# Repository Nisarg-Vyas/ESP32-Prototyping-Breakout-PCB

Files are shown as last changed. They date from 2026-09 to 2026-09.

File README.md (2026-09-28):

# ESP32 Prototyping & Breakout Board

A custom PCB designed to make ESP32 prototyping easier, faster, and more convenient than working directly on a breadboard or perfboard.

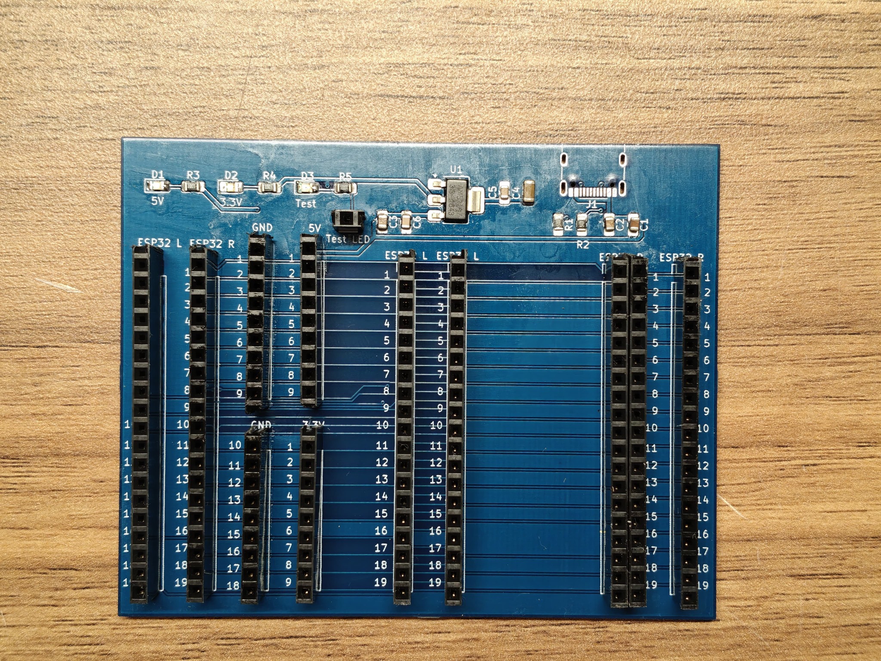
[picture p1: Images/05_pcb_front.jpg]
ESP32 Prototyping Breakout Board


## Overview

When working with ESP32 development boards, the physical form factor can make breadboard prototyping inconvenient. In particular, larger ESP32 boards can occupy a large portion of a breadboard and restrict convenient access to the pins on both sides.

A perfboard can solve some of these problems, but manually wiring a large number of closely spaced GPIO connections is tedious and time-consuming.

This project was created as a reusable PCB-based prototyping platform. The ESP32 is mounted on the board while its pins are brought out to multiple accessible header rows. The board also provides dedicated power and ground connections and supports more than one ESP32 development-board form factor.

The goal is not to replace a breadboard for every project, but to make repeated ESP32 prototyping cleaner and faster.

## Motivation

The project started from a simple practical problem:

- A larger ESP32 development board does not leave convenient access to both sides of a breadboard.
- Connecting peripherals to both sides of the ESP32 can therefore become awkward.
- Dense adjacent GPIO connections on a perfboard require a lot of manual soldering.
- A custom PCB provides a repeatable layout that can be reused across multiple ESP32 prototypes.
- Since the board was already being designed for the larger ESP32 form factor, the layout was made compatible with a smaller ESP32 board as well.

### Breadboard vs. Custom PCB

The photographs in `Images/` show the motivation for the design.

The larger ESP32 board occupies a significant area of the breadboard, limiting convenient access to the surrounding rows. The custom PCB instead places the ESP32 in the center and distributes its connections across accessible header rows.

## Features

- ESP32 pin breakout through multiple 2.54 mm header rows
- Dedicated GND connections
- Dedicated 5 V connections
- Dedicated 3.3 V connections
- USB Type-C input circuit on the PCB
- USB Type-C CC resistors
- AMS1117-3.3 V linear regulator
- Regulator input/output capacitors
- 5 V indicator LED
- 3.3 V indicator LED
- Separate test LED
- Through-hole headers with SMD supporting circuitry
- Designed for multiple ESP32 development-board form factors
- Compact custom PCB: approximately **87.62 mm × 70 mm**
- Final PCB layout completed with no unrouted connections in KiCad

> **Note:** The USB Type-C connector itself has not yet been sourced by me, so it is **not soldered onto the current physical PCB**. The connector footprint and supporting circuitry are present in the PCB design, but the current prototype does not have the Type-C connector populated.

## Hardware Design

### Block Diagram

```text
                    USB Type-C
                        |
                        v
                    5 V Rail
                   /       \
                  /         \
             5 V LED      AMS1117-3.3
                              |
                              v
                         3.3 V Rail
                              |
                              v
                           ESP32
                              |
             +----------------+----------------+
             |                |                |
          GPIO Headers     GND Headers     Power Headers
```

### Schematic

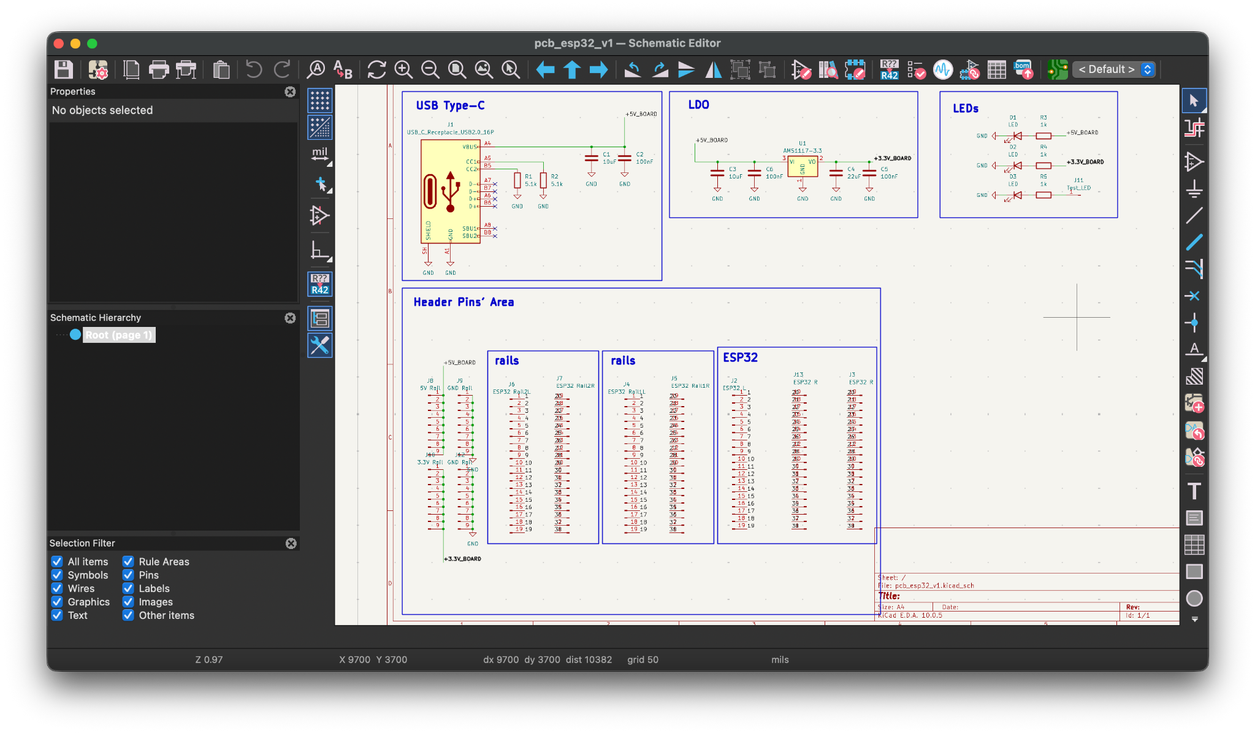
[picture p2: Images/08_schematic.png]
Schematic


The schematic is divided into:

- USB Type-C input
- 3.3 V regulation
- Indicator LEDs
- ESP32 header connections
- Power and ground rails

## PCB Design

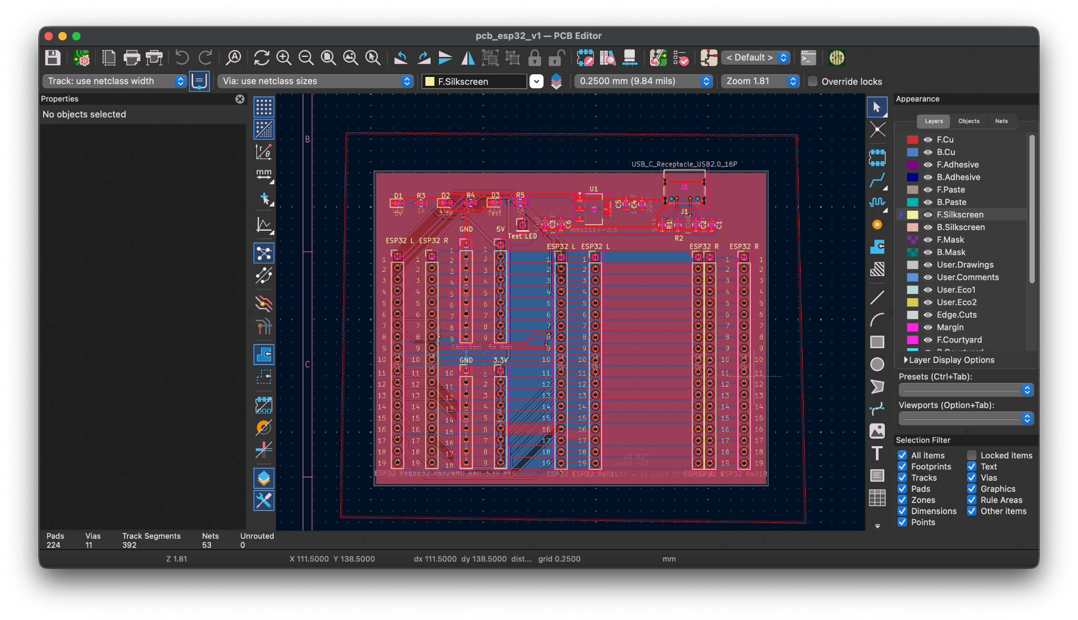
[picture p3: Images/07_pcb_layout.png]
PCB Layout


The board was designed in **KiCad**.

The layout contains multiple parallel ESP32 header rows so that the ESP32 connections remain accessible while the ESP32 is mounted on the board.

The final PCB has:

- Board size: **87.62 mm × 70 mm**
- 2.54 mm header spacing
- SMD power/regulator circuitry
- Through-hole ESP32/header connections
- USB Type-C footprint and supporting circuit
- Dedicated power and ground access

## Physical Board

### PCB without ESP32

PCB front

The board exposes the ESP32 connections through the surrounding header rows.

### PCB with larger ESP32

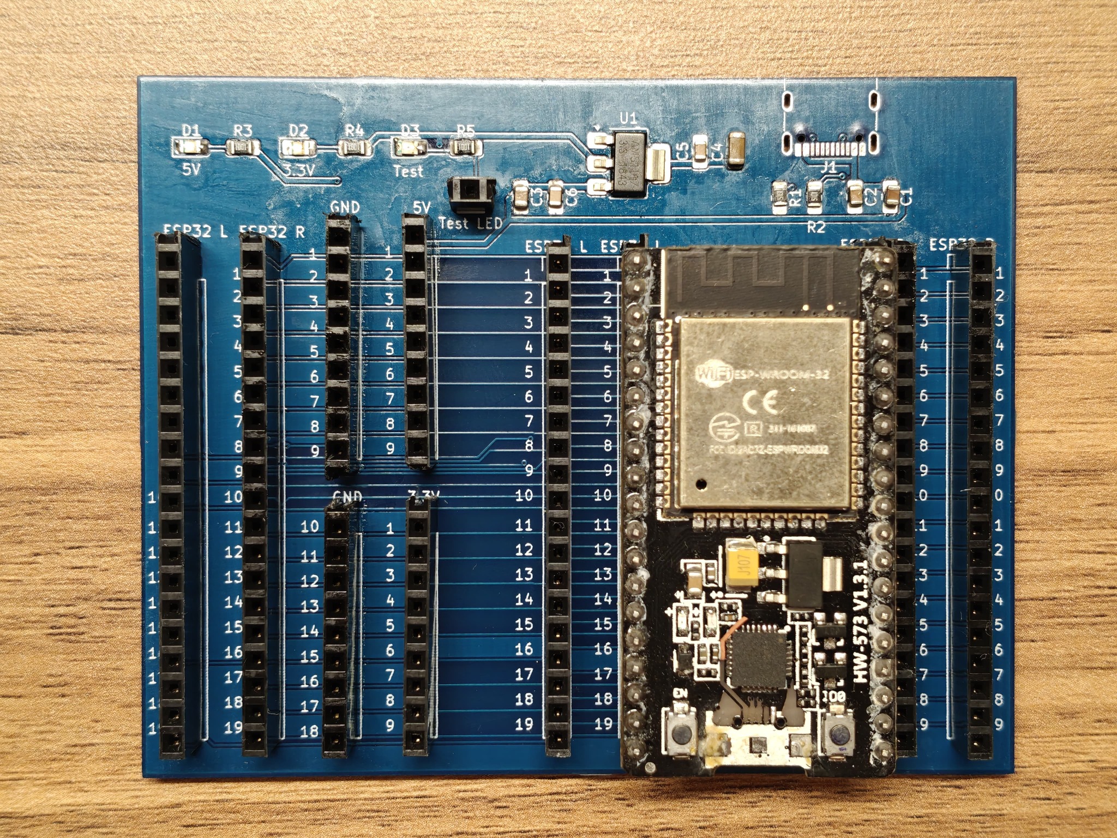
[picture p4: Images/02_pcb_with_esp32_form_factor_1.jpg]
Larger ESP32 on PCB


The larger ESP32 development board fits into the central position while leaving the breakout headers accessible.

### PCB with smaller ESP32

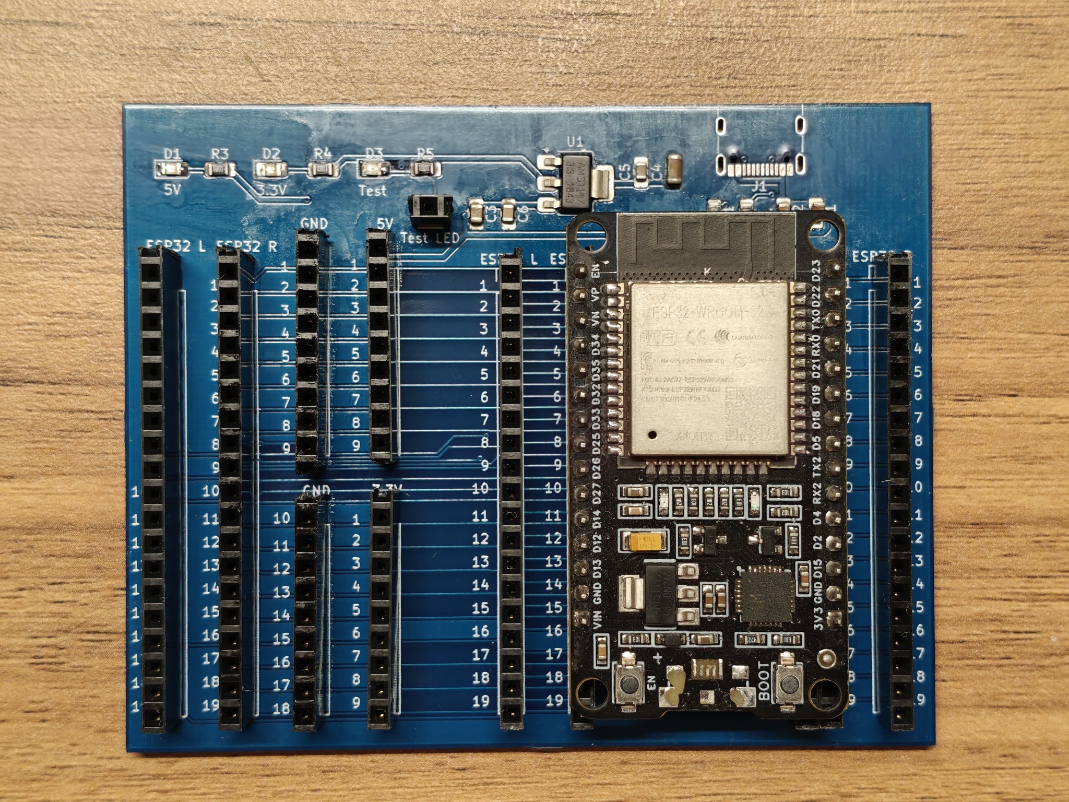
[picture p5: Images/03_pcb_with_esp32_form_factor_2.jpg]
Smaller ESP32 on PCB


The board was also designed to accommodate a smaller ESP32 development-board form factor.

### ESP32 on a Breadboard

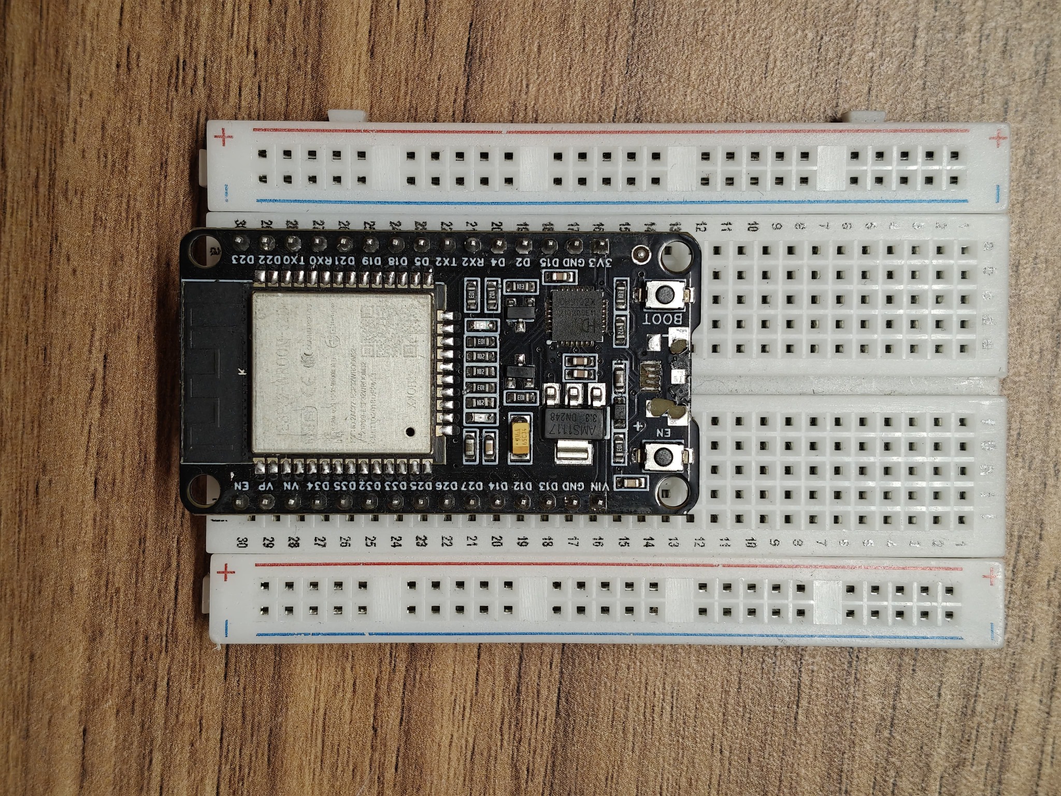
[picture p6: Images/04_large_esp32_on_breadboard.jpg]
ESP32 on breadboard


This comparison illustrates the original motivation for the project: using a larger ESP32 board directly on a breadboard can make access to both sides inconvenient.

### Back of the PCB

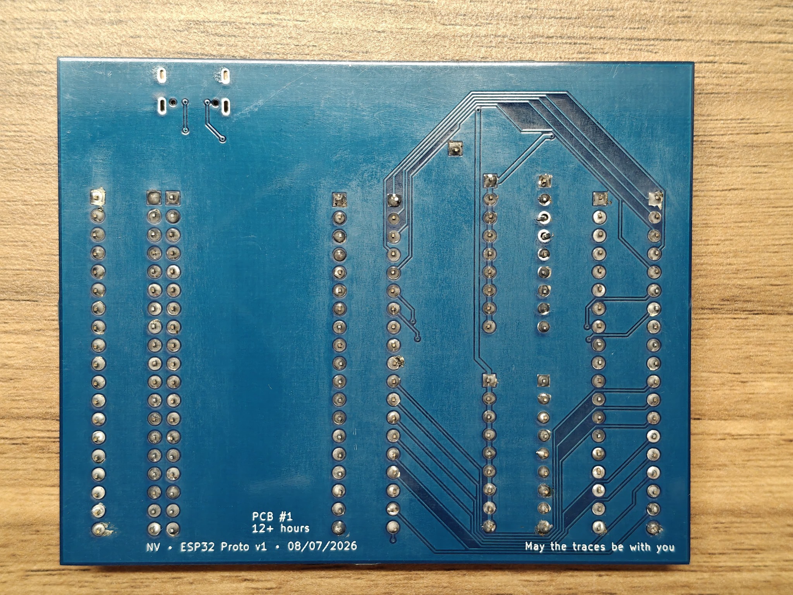
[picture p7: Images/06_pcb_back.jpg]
PCB back


The back side shows the routing and the first-board markings:

> PCB #1 — 12+ hours  
> NV • ESP32 Proto v1 • 08/07/2026  
> May the traces be with you

## Pinout

The header arrangement uses the **ESP32 module pin numbers** used in the KiCad schematic.

The pinout documentation is available in:

[`Documentation/Pinout.md`](Documentation/Pinout.md)

The four 19-pin breakout rows are arranged as paired groups:

- One row exposes ESP32 module pins **1–19**
- The paired row exposes ESP32 module pins **20–38**

This arrangement is repeated for the supported ESP32 board positions.

> The schematic uses the module's physical pin numbers (1–38). It does not label these connections with GPIO names, so the pinout document intentionally preserves the numbering used by the design rather than introducing a separate GPIO mapping.

## Design Files

The `KiCad/` directory contains the editable KiCad project:

```text
KiCad/
├── pcb_esp32_v1.kicad_pro
├── pcb_esp32_v1.kicad_sch
└── pcb_esp32_v1.kicad_pcb
```

### Fabrication Files

The `Fabrication/` directory is intended for files required to reproduce the physical board:

```text
Fabrication/
├── final_gerbers.zip
└── bom.csv
```

### Gerbers

Gerber files describe the PCB layers and board geometry used by a PCB manufacturer to fabricate the bare PCB.

### Bill of Materials (BOM)

The BOM lists the components required to assemble the board, including their references, values, footprints, and quantities.

A CSV BOM can be placed in:

```text
Fabrication/bom.csv
```

## Repository Structure

```text
ESP32-Prototyping-Breakout/
│
├── README.md
├── LICENSE
├── .gitignore
│
├── KiCad/
│   ├── pcb_esp32_v1.kicad_pro
│   ├── pcb_esp32_v1.kicad_sch
│   └── pcb_esp32_v1.kicad_pcb
│
├── Fabrication/
│   ├── final_gerbers.zip
│   └── bom.csv
│
├── Documentation/
│   └── Pinout.md
│
└── Images/
    ├── 01_esp32_on_breadboard.jpg
    ├── 02_pcb_with_esp32_form_factor_1.jpg
    ├── 03_pcb_with_esp32_form_factor_2.jpg
    ├── 04_large_esp32_on_breadboard.jpg
    ├── 05_pcb_front.jpg
    ├── 06_pcb_back.jpg
    ├── 07_pcb_layout.png
    └── 08_schematic.png
```

## Project Status

**Version:** v1

This is a personal prototype and my first custom PCB design.

The physical board was fabricated and assembled for ESP32 prototyping and experimentation.

The current physical prototype has the USB Type-C connector footprint unpopulated because the connector has not yet been sourced.

The board was designed as a practical development aid rather than as a production-ready commercial board.

## Future Improvements

Possible improvements for a future revision include:

- Populate and validate the USB Type-C connector
- More clearly standardized pin labels
- Additional protection circuitry
- Improved mechanical mounting options
- Additional prototyping headers
- Further optimization of board size and routing
- Additional ESP32 development-board compatibility

## Tools

- **KiCad** — schematic capture and PCB design
- **PCB fabrication** — custom manufactured PCB
- **ESP32 development boards** — hardware validation and prototyping

## License

This hardware design and associated documentation are released under the MIT License. See [`LICENSE`](LICENSE) for details.

## Author

**Nisarg Vyas**

Computer Science & Engineering

---

> *PCB #1 — 12+ hours*  
> *May the traces be with you.*

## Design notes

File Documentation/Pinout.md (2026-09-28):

# ESP32 Prototyping & Breakout Board — Pinout

This document describes the header arrangement used in the PCB design.

## Important: Pin Numbering

The KiCad schematic labels the ESP32 connections using the **physical ESP32 module pin numbers 1–38**.

These numbers are **not GPIO numbers**.

The board therefore uses the same numbering convention as the schematic so that the physical PCB, schematic, and layout remain consistent.

For the GPIO function associated with a physical ESP32 module pin, refer to the pinout of the specific ESP32 development board/module being used.

## 19-Pin Header Arrangement

Each side of the ESP32 module is represented by a 19-pin header.

### ESP32 Module Pins 1–19

| Header Pin | ESP32 Module Pin |
|---:|---:|
| 1 | 1 |
| 2 | 2 |
| 3 | 3 |
| 4 | 4 |
| 5 | 5 |
| 6 | 6 |
| 7 | 7 |
| 8 | 8 |
| 9 | 9 |
| 10 | 10 |
| 11 | 11 |
| 12 | 12 |
| 13 | 13 |
| 14 | 14 |
| 15 | 15 |
| 16 | 16 |
| 17 | 17 |
| 18 | 18 |
| 19 | 19 |

### ESP32 Module Pins 20–38

The paired 19-pin header exposes the remaining physical module pins.

| Header Pin | ESP32 Module Pin |
|---:|---:|
| 1 | 20 |
| 2 | 21 |
| 3 | 22 |
| 4 | 23 |
| 5 | 24 |
| 6 | 25 |
| 7 | 26 |
| 8 | 27 |
| 9 | 28 |
| 10 | 29 |
| 11 | 30 |
| 12 | 31 |
| 13 | 32 |
| 14 | 33 |
| 15 | 34 |
| 16 | 35 |
| 17 | 36 |
| 18 | 37 |
| 19 | 38 |

## Power and Ground Rails

The board also provides dedicated headers for the board-level power rails:

| Rail | Purpose |
|---|---|
| 5V Rail | Access to the board's 5 V supply |
| 3.3V Rail | Access to the regulated 3.3 V supply |
| GND Rail | Ground connection |

These rails are intended to simplify connections to sensors, modules, and other peripherals during prototyping.

## Test LED

A separate header is provided for the test LED connection.

| Connection | Description |
|---|---|
| Test LED | External access to the test LED connection |

## ESP32 Form Factors

The PCB contains multiple ESP32 header arrangements so that the same prototyping platform can be used with different ESP32 development-board sizes.

The exact mechanical compatibility depends on the physical pin spacing and board dimensions of the ESP32 development board.

## Schematic Reference

For the authoritative electrical connections, refer to:

```text
KiCad/pcb_esp32_v1.kicad_sch
```

For the physical placement and routing, refer to:

```text
KiCad/pcb_esp32_v1.kicad_pcb
```

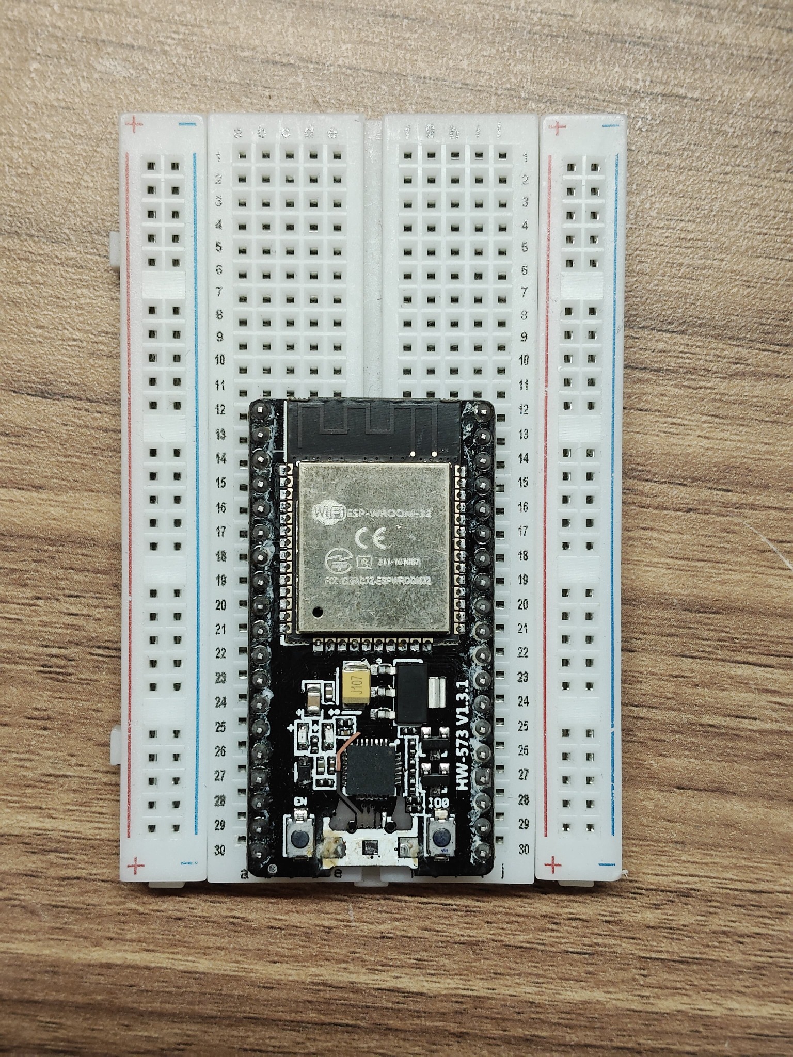
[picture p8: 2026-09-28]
Images/01_esp32_on_breadboard.jpg

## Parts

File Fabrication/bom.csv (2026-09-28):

Reference | Qty | Value | DNP | Exclude from BOM | Exclude from Board | Footprint | Datasheet
C1,C3 | 2 | 10uF |  |  |  | Capacitor_SMD:C_0805_2012Metric_Pad1.18x1.45mm_HandSolder
C2,C5,C6 | 3 | 100nF |  |  |  | Capacitor_SMD:C_0805_2012Metric_Pad1.18x1.45mm_HandSolder
C4 | 1 | 22uF |  |  |  | Capacitor_SMD:C_0805_2012Metric_Pad1.18x1.45mm_HandSolder
D1,D2,D3 | 3 | LED |  |  |  | LED_SMD:LED_0805_2012Metric_Pad1.15x1.40mm_HandSolder
J1 | 1 | USB_C_Receptacle_USB2.0_16P |  |  |  | Connector_USB:USB_C_Receptacle_G-Switch_GT-USB-7010ASV | https://www.usb.org/sites/default/files/documents/usb_type-c.zip
J2 | 1 | ESP32 L |  |  |  | Connector_PinHeader_2.54mm:PinHeader_1x19_P2.54mm_Vertical
J3,J13 | 2 | ESP32 R |  |  |  | Connector_PinHeader_2.54mm:PinHeader_1x19_P2.54mm_Vertical
J4 | 1 | ESP32 Rail1L |  |  |  | Connector_PinHeader_2.54mm:PinHeader_1x19_P2.54mm_Vertical
J5 | 1 | ESP32 Rail1R |  |  |  | Connector_PinHeader_2.54mm:PinHeader_1x19_P2.54mm_Vertical
J6 | 1 | ESP32 Rail2L |  |  |  | Connector_PinHeader_2.54mm:PinHeader_1x19_P2.54mm_Vertical
J7 | 1 | ESP32 Rail2R |  |  |  | Connector_PinHeader_2.54mm:PinHeader_1x19_P2.54mm_Vertical
J8 | 1 | 5V Rail |  |  |  | Connector_PinHeader_2.54mm:PinHeader_1x09_P2.54mm_Vertical
J9,J12 | 2 | GND Rail |  |  |  | Connector_PinHeader_2.54mm:PinHeader_1x09_P2.54mm_Vertical
J10 | 1 | 3.3V Rail |  |  |  | Connector_PinHeader_2.54mm:PinHeader_1x09_P2.54mm_Vertical
J11 | 1 | Test_LED |  |  |  | Connector_PinHeader_2.54mm:PinHeader_1x01_P2.54mm_Vertical
R1,R2 | 2 | 5.1k |  |  |  | Resistor_SMD:R_0805_2012Metric_Pad1.20x1.40mm_HandSolder
R3,R4,R5 | 3 | 1k |  |  |  | Resistor_SMD:R_0805_2012Metric_Pad1.20x1.40mm_HandSolder
U1 | 1 | AMS1117-3.3 |  |  |  | Package_TO_SOT_SMD:SOT-223-3_TabPin2 | http://www.advanced-monolithic.com/pdf/ds1117.pdf

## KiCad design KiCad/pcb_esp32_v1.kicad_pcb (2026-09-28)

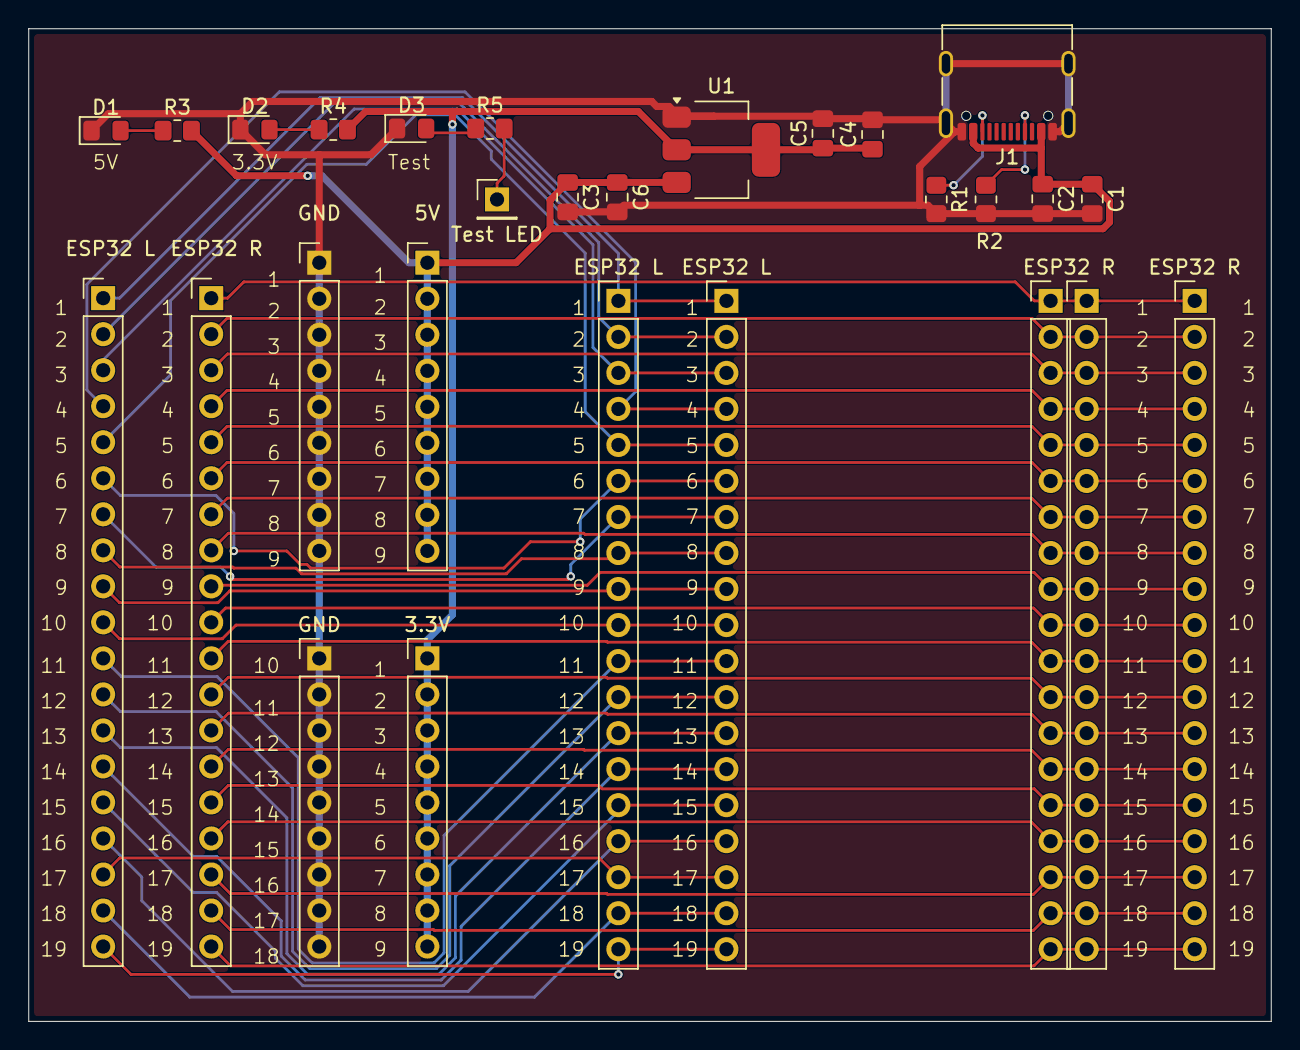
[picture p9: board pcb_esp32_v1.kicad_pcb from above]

Board: 2 copper layers, 87.6 x 70.0 mm, 28 parts (0 on the bottom side), 47 nets.

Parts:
3.3V: 3.3V Rail; PinHeader_1x09_P2.54mm_Vertical
5V: 5V Rail; PinHeader_1x09_P2.54mm_Vertical
C1, C3: 10uF; C_0805_2012Metric_Pad1.18x1.45mm_HandSolder
C2, C5, C6: 100nF; C_0805_2012Metric_Pad1.18x1.45mm_HandSolder
C4: 22uF; C_0805_2012Metric_Pad1.18x1.45mm_HandSolder
D1, D2, D3: LED; LED_0805_2012Metric_Pad1.15x1.40mm_HandSolder
ESP32 L: ESP32 Rail1L; PinHeader_1x19_P2.54mm_Vertical
ESP32 L#2: ESP32 L; PinHeader_1x19_P2.54mm_Vertical
ESP32 L#3: ESP32 Rail2L; PinHeader_1x19_P2.54mm_Vertical
ESP32 R: ESP32 R; PinHeader_1x19_P2.54mm_Vertical
ESP32 R#2: ESP32 Rail1R; PinHeader_1x19_P2.54mm_Vertical
ESP32 R#3: ESP32 Rail2R; PinHeader_1x19_P2.54mm_Vertical
GND: GND Rail; PinHeader_1x09_P2.54mm_Vertical
GND#2: GND Rail; PinHeader_1x09_P2.54mm_Vertical
J1: USB_C_Receptacle_USB2.0_16P; USB_C_Receptacle_G-Switch_GT-USB-7010ASV
J3: ESP32 R; PinHeader_1x19_P2.54mm_Vertical
R1, R2: 5.1k; R_0805_2012Metric_Pad1.20x1.40mm_HandSolder
R3, R4, R5: 1k; R_0805_2012Metric_Pad1.20x1.40mm_HandSolder
Test LED: Test_LED; PinHeader_1x01_P2.54mm_Vertical
U1: AMS1117-3.3; SOT-223-3_TabPin2

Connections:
/1: ESP32 L.1, ESP32 L#2.1, ESP32 L#3.1
/2: ESP32 L.2, ESP32 L#2.2, ESP32 L#3.2
/3: ESP32 L.3, ESP32 L#2.3, ESP32 L#3.3
/4: ESP32 L.4, ESP32 L#2.4, ESP32 L#3.4
/5: ESP32 L.5, ESP32 L#2.5, ESP32 L#3.5
/6: ESP32 L.6, ESP32 L#2.6, ESP32 L#3.6
/7: ESP32 L.7, ESP32 L#2.7, ESP32 L#3.7
/8: ESP32 L.8, ESP32 L#2.8, ESP32 L#3.8
/9: ESP32 L.9, ESP32 L#2.9, ESP32 L#3.9
/10: ESP32 L.10, ESP32 L#2.10, ESP32 L#3.10
/11: ESP32 L.11, ESP32 L#2.11, ESP32 L#3.11
/12: ESP32 L.12, ESP32 L#2.12, ESP32 L#3.12
/13: ESP32 L.13, ESP32 L#2.13, ESP32 L#3.13
/14: ESP32 L.14, ESP32 L#2.14, ESP32 L#3.14
/15: ESP32 L.15, ESP32 L#2.15, ESP32 L#3.15
/16: ESP32 L.16, ESP32 L#2.16, ESP32 L#3.16
/17: ESP32 L.17, ESP32 L#2.17, ESP32 L#3.17
/18: ESP32 L.18, ESP32 L#2.18, ESP32 L#3.18
/19: ESP32 L.19, ESP32 L#2.19, ESP32 L#3.19
/20: ESP32 R.19, ESP32 R#2.19, ESP32 R#3.19, J3.19
/21: ESP32 R.18, ESP32 R#2.18, ESP32 R#3.18, J3.18
/22: ESP32 R.17, ESP32 R#2.17, ESP32 R#3.17, J3.17
/23: ESP32 R.16, ESP32 R#2.16, ESP32 R#3.16, J3.16
/24: ESP32 R.15, ESP32 R#2.15, ESP32 R#3.15, J3.15
/25: ESP32 R.14, ESP32 R#2.14, ESP32 R#3.14, J3.14
/26: ESP32 R.13, ESP32 R#2.13, ESP32 R#3.13, J3.13
/27: ESP32 R.12, ESP32 R#2.12, ESP32 R#3.12, J3.12
/28: ESP32 R.11, ESP32 R#2.11, ESP32 R#3.11, J3.11
/29: ESP32 R.10, ESP32 R#2.10, ESP32 R#3.10, J3.10
/30: ESP32 R.9, ESP32 R#2.9, ESP32 R#3.9, J3.9
/31: ESP32 R.8, ESP32 R#2.8, ESP32 R#3.8, J3.8
/32: ESP32 R.7, ESP32 R#2.7, ESP32 R#3.7, J3.7
/33: ESP32 R.6, ESP32 R#2.6, ESP32 R#3.6, J3.6
/34: ESP32 R.5, ESP32 R#2.5, ESP32 R#3.5, J3.5
/35: ESP32 R.4, ESP32 R#2.4, ESP32 R#3.4, J3.4
/36: ESP32 R.3, ESP32 R#2.3, ESP32 R#3.3, J3.3
/37: ESP32 R.2, ESP32 R#2.2, ESP32 R#3.2, J3.2
/38: ESP32 R.1, ESP32 R#2.1, ESP32 R#3.1, J3.1
/+3.3V_BOARD: 3.3V.1, 3.3V.2, 3.3V.3, 3.3V.4, 3.3V.5, 3.3V.6, 3.3V.7, 3.3V.8, 3.3V.9, C4.1, C5.1, R4.2, U1.2 (VO)
/+5V_BOARD: 5V.1, 5V.2, 5V.3, 5V.4, 5V.5, 5V.6, 5V.7, 5V.8, 5V.9, C1.1, C2.1, C3.1, C6.1, J1.A4 (VBUS), J1.A9 (VBUS), J1.B4 (VBUS), J1.B9 (VBUS), R3.2, U1.3 (VI)
GND: C1.2, C2.2, C3.2, C4.2, C5.2, C6.2, D1.1 (K), D2.1 (K), D3.1 (K), GND.1, GND.2, GND.3, GND.4, GND.5, GND.6, GND.7, GND.8, GND.9, GND#2.1, GND#2.2, GND#2.3, GND#2.4, GND#2.5, GND#2.6, GND#2.7, GND#2.8, GND#2.9, J1.A1 (GND), J1.A12 (GND), J1.B1 (GND), J1.B12 (GND), J1.SH (SHIELD), R1.2, R2.2, U1.1 (GND)
unnamed: D1.2 (A), R3.1
unnamed: D2.2 (A), R4.1
unnamed: D3.2 (A), R5.1
unnamed: J1.A5 (CC1), R2.1
unnamed: J1.B5 (CC2), R1.1
unnamed: R5.2, Test LED.1 (Pin_1_1)

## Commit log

2026-09-28 added 2 files
    [pcb_esp32_v1.kicad_pcb, pcb_esp32_v1.kicad_sch]
2026-09-28 added new files
    [pcb_esp32_v1.csv]
2026-09-28 readme changes
    [bom.csv]
